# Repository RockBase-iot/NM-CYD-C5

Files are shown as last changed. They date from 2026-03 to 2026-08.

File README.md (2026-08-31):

# NM-CYD-C5

English | [中文](README_zh.md)

NM-CYD-C5 is a Cheap Yellow Display (CYD) based on ESP32-C5, supporting dual-band Wi-Fi 6 / BLE 5 / Thread / Zigbee.

This development board features an ESP32-C5 with a built-in 320 × 240 2.8" LCD touchscreen, similar to the [ESP32-Cheap-Yellow-Display](https://github.com/witnessmenow/ESP32-Cheap-Yellow-Display). The default LCD driver is ST7789, and it can also be changed to the ILI9341 driver.

# Features

The NM-CYD-C5 has the following features:

- ESP32-C5-WROOM-1, 16MB Flash and 8MB PSRAM
- 320 × 240 LCD Display (2.8")
- Resistive Touch Screen
- ESP32-C5 USB Type-C port and USB Type-C to UART port (CH340), for powering and programming
- SD Card Slot, RGB LED and some additional pins
- Fully compatible dimensions and interfaces with ESP32-Cheap-Yellow-Display, enabling seamless replacement
- FPC connector added for more convenient connection to external modules

## New Features of ESP32-C5

- ESP32-C5 RISC-V 32-bit @ 240 MHz
- Dual-Band Wi-Fi 6: 2.4GHz & 5GHz (802.11ax)
- Bluetooth 5: Classic and BLE 5 with SPP, HID, GATT support
- IEEE 802.15.4: Zigbee 3.0 end-device support
- Thread: IPv6-based mesh networking protocol

| Component | Specification |
|:---:|:---:|
| **Main SoC** | ESP32-C5 (RISC-V 32-bit, 240MHz) |
| **Wireless Protocols** | Wi-Fi 6 (802.11ax) 2.4/5GHz + BLE 5.3 + IEEE 802.15.4 |
| **Display** | 2.8" TFT, 240×320, ST7789, Touch Screen |
| **Memory** | 16MB Flash + 8MB PSRAM |
| **Interface** | 2× USB-C, GPIO, Micro SD Card Slot |

# Where to Buy

You can get the NM-CYD-C5 from the RockBase IoT AliExpress store, the RockBase IoT official website, or from NMTech Stores.

- [RockBase IoT Store](https://www.aliexpress.com/store/1105401362)
- [RockBase Shop](https://rockbase.shop/products/nm-cyd-c5)
- [NMTech Global Store](https://www.aliexpress.com/store/1104265822)
- [NMMiner](https://www.nmminer.com)

# Getting Started with Your NM-CYD-C5

For details on how to get started with your NM-CYD-C5, please check out the [Setup and Configuration](https://wiki.rockbaseiot.com/docs/products/nm-cyd-c5/) page.

To work with NM-CYD-C5, you should use the newest espressif32 library, version 3.3.5 or higher.

```ini
[env]
platform = https://github.com/pioarduino/platform-espressif32/releases/download/55.03.36/platform-espressif32.zip ; Arduino 3.3.6
```

When you use TFT_eSPI to work with the LCD, you should add `TFT_eSPI_ESP32_C5.c/h` to the Processors directory, and update `TFT_eSPI.c/h` with `CONFIG_IDF_TARGET_ESP32C5`.
These files can be found in `Demos\Arduino\libraries\TFT_eSPI`.

## Pinout of NM-CYD-C5

### Using ST7789 with XPT2046 for Touchscreen, Shared SPI

| Device | SCK | MISO | MOSI | CS | IRQ |
| --- | :---: | :---: | :---: | :---: | :---: |
| Display | 6 | 2 | 7 | 23 | --- |
| Touch | 6 | 2 | 7 | 1 | --- |
| SD Card | 6 | 2 | 7 | 10 | --- |

### LP-UART (`NM-CYD-C5:P5`) for GPS Module, e.g. `NM-ATGM336H`, Plug and Play

| Device | RX | TX | GPIO |
| --- | :---: | :---: | :---: |
| GPS | 4 | 5 | --- |

### Extend IO for I2C, `NM-CYD-C5: CN1`

| 1 | 2 | 3 | 4 |
|---|---|---|---|
| 3.3V | IO9 | IO8 | GND |

### Extend IO, `NM-CYD-C5: P1`

| 1 | 2 | 3 | 4 |
|---|---|---|---|
| IO4 | IO8 | IO26 | GND |

### NM Extend IO: 12-Pin FPC Interface, `NM-CYD-C5: FPC2`

| 1 | 2 | 3 | 4 | 5 | 6 | 7 | 8 | 9 | 10 | 11 | 12 |
|---|---|---|---|---|---|---|---|---|---|---|---|
| IO2 | IO6 | IO7 | IO10 | GND | IO4 | IO8 | IO5 | IO9 | USB D- | USB D+ | GND |

### WS2812 LEDC and Screen Backlight

| NM-CYD-C5 | Pin |
| :---: | :---: |
| IO25 | Display BL |
| IO27 | WS2812 RGB LED |

NM-CYD-C5-Pinout

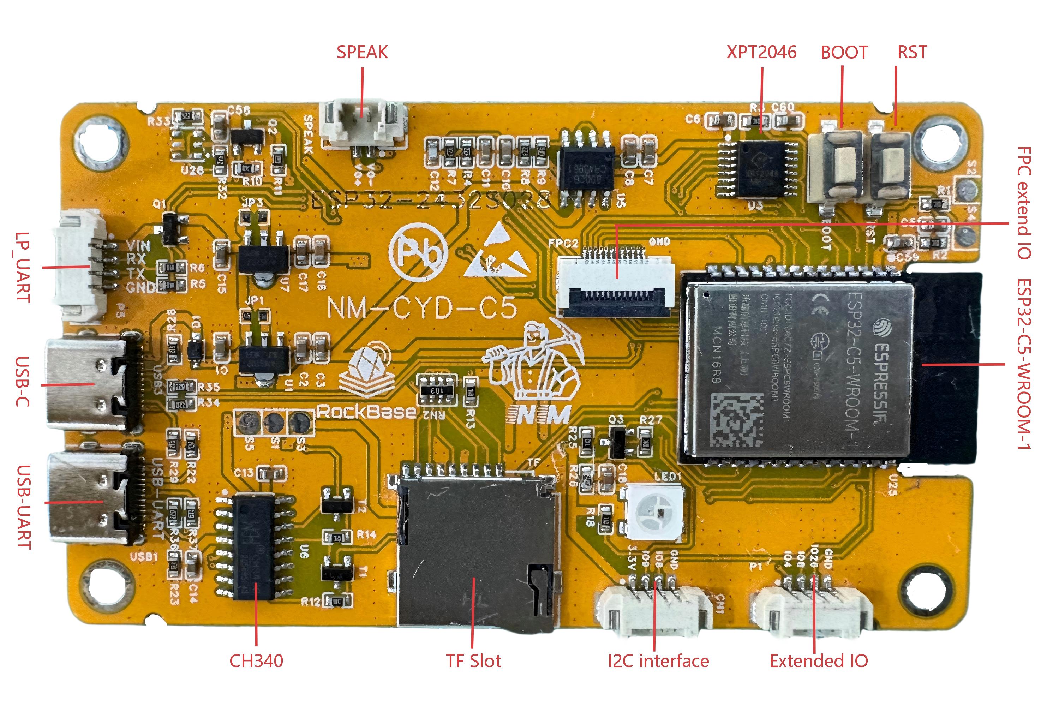
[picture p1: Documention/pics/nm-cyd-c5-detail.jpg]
NM-CYD-C5 detail


## The NM-CYD-C5 Colorful Special Edition

The [RockBase IoT Colorful Special Edition](https://rockbase.shop/products/nm-cyd-c5-colorful) will be released soon and is compatible with the standard NM-CYD-C5.

NM-CYD-C5-Color

NM-CYD-C5-Colorful

## The NM-CYD-C5 External Antenna Board

In response to widespread user demand, the latest batch of NM-CYD-C5-Colorful includes a new external-antenna design, available as an option. The NM-CYD-C5-Colorful-Ant comes with an IPEX 1 cable and a dual-band 2.4G/5G antenna, making it easy to use an external antenna. The external-antenna version of the NM-CYD-C5-Colorful delivers better Wi-Fi and BLE signal reception, making it suitable for users with higher wireless-performance requirements.

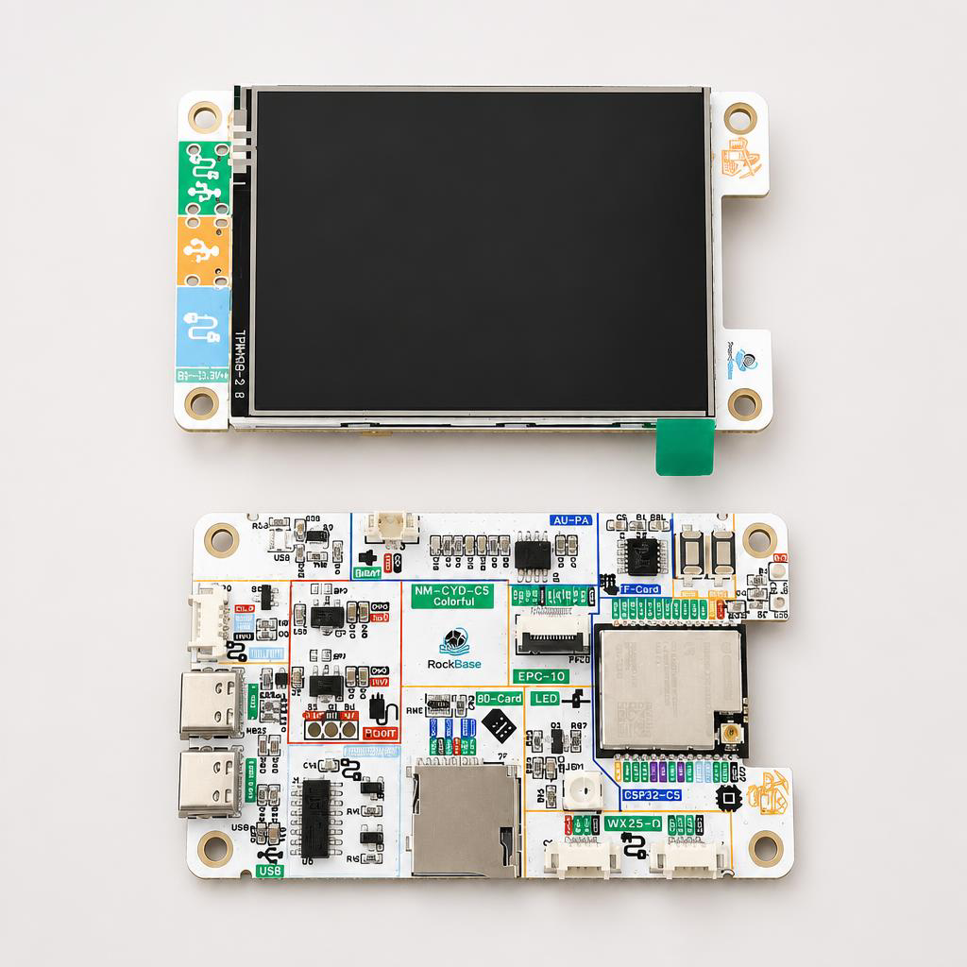
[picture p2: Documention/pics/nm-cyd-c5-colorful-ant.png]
NM-CYD-C5-Colorful-Antenna


### External Antenna Parameters

- Frequency range: 2400~2500MHz / 5000~5800MHz
- VSWR: 2400-2500 ≤ 2.5, 5000-5800 ≤ 2.5
- Efficiency %: 2400-2500: 83.3 AVG; 5000-5800: 73.8 AVG
- Peak Gain (dBi): 2400-2500: 3.2 AVG; 5000-5800: 3.7 AVG
- Radiation Properties: Omni-directional
- Polarization: Linear

<table>
  <tr>
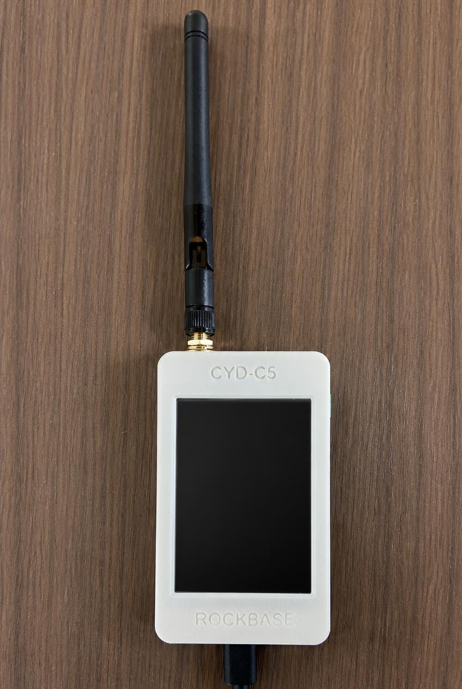
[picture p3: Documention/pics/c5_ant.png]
    <td></td>
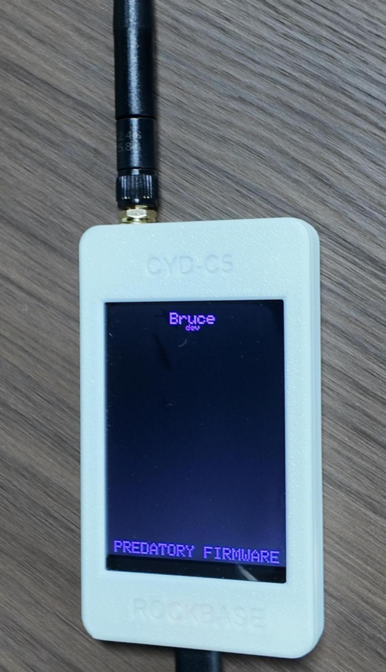
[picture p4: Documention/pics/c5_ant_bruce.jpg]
    <td></td>
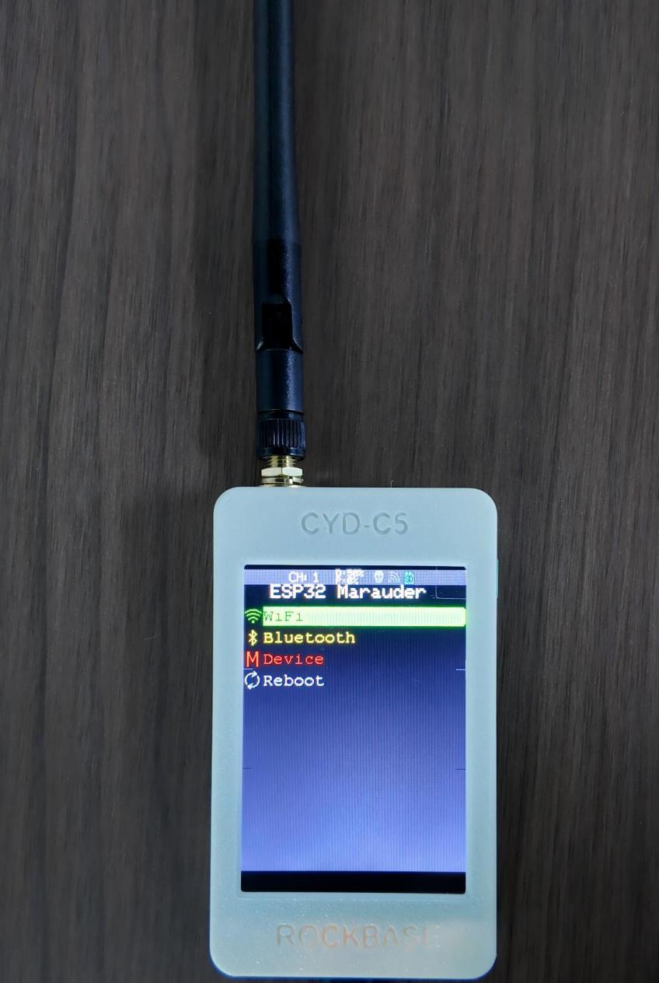
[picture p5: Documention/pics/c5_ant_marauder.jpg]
    <td></td>
  </tr>
</table>

## Compare with ESP32-2432S028

| Feature | Standard CYD (ESP32) | NM-CYD-C5 |
| :---: | :---: | :---: |
| **Wi-Fi Band** | 2.4GHz | 2.4+5GHz |
| **Wi-Fi Standard** | 802.11 b/g/n | 802.11ax (Wi-Fi 6) |
| **ZigBee** | None | ZigBee 3.0 |
| **Thread** | None | Thread 1.3 |
| **Flash** | 4MB | 16MB |
| **PSRAM** | None | 8MB |

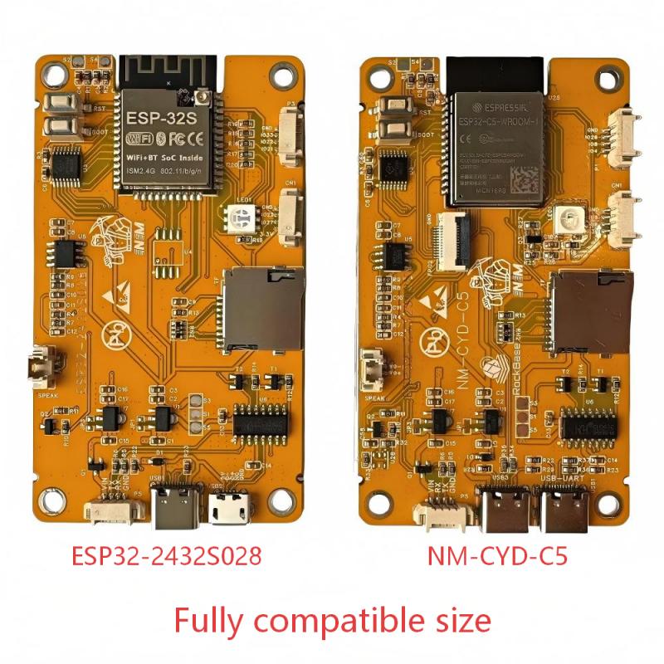
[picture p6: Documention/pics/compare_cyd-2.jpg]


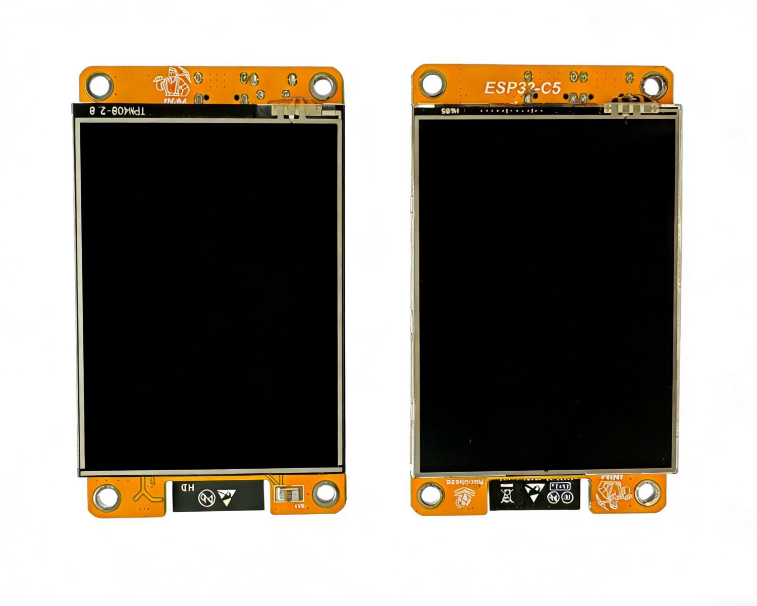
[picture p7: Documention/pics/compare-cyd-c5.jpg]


# Supported Projects

## Already Supported Projects

- [NMMiner](https://github.com/NMminer1024/NMMiner)
- [Brucefw](https://github.com/BruceDevices/firmware)
- [ESP32Marauder](https://github.com/RockBase-iot/ESP32Marauder)
- [Rogue-Radar](https://github.com/RockBase-iot/Rogue-Radar-CYD)

    Rogue Radar is a handheld ESP32 firmware that combines multiple wireless and utility tools into one rotary-driven interface.

- [CYM (Cheap Yellow Monster)](https://github.com/JimGat/CYM-NM28C5)

    Cheap Yellow Monster is a portable, touchscreen-driven WiFi security toolkit running on the NM-CYD-C5.

- [Launcher](https://github.com/RockBase-iot/Launcher)

    Application launcher for M5Stack, Lilygo, CYDs, Marauder and ESP32 devices.

- [ESP-Claw](https://github.com/espressif/esp-claw)

    ESP-Claw is Espressif's chat-coding AI agent framework for IoT devices. It defines device behavior through conversation and completes the full loop of sensing, decision-making, and execution locally on Espressif chips. Inspired by the OpenClaw concept and reimplemented in C, ESP-Claw is lightweight, intelligent, and continuously evolving.

    

    *New Version Released*: ESP-Claw 0.3.0 has been updated to support NM-CYD-C5, merging new features from `espressif/master`.

If you just want to flash the firmware, you can try the [RockBase IoT Web Flasher](https://flash.rockbaseiot.com) and choose device type `nm-cyd-c5`.

If you would like your firmware or project to run on the NM-CYD-C5, please contact the RockBase IoT team and we will assist you with adaptation and testing.

For firmware you would like to offer as a download on our Web Flasher, please check out the [ESPWebApps](https://github.com/RockBase-iot/ESPWebApps) project. ESPWebApps is a web application management platform based on ESP32 that allows users to run and manage multiple web applications on the ESP32. With ESPWebApps, you can easily share your projects with NM-CYD-C5 users, making it simple to download, install, update, and run applications on the NM-CYD-C5.

## Ongoing Projects

- [HaleHound-CYD](https://github.com/JesseCHale/HaleHound-CYD)
- [ESP32-KillerBee](https://github.com/RockBase-iot/ESP32-KillerBee)
- [ESP32DualBandWardriver](https://github.com/justcallmekoko/ESP32DualBandWardriver)

# Release Log

## 2026-08-31

- Added the external-antenna version (`NM-CYD-C5-Colorful-Ant`) description and antenna parameters.
- Added external-antenna enclosure 3MF files:
  - [nm-cyd-c5-ant-upper.3mf](Documention/3-case/nm-cyd-c5-ant-upper.3mf)
  - [nm-cyd-c5-ant-bottom.3mf](Documention/3-case/nm-cyd-c5-ant-bottom.3mf)

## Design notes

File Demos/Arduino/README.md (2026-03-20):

# How use NM-CYD-C5 with Arduino

## 1. Add ESP32 Board Support
1. Go to `File`->`Preferences`

2. Add to "Additional Boards Manager URLs":

   ```
   https://espressif.github.io/arduino-esp32/package_esp32_index.json
   ```

3. Go to `Tools`->`Board`->`Boards Manager`

4. Search "ESP32" and install "ESP32 by Espressif Systems", the version 3.3.5 or a higher version can support ESP32-C5.

5. Then choose `ESP32C5 Dev Module` from `Tools`->`Board`->`esp32`->`ESP32C5 Dev Module`.

## 2. Install the libraries

Arduino IDE Libray Manger, Install the libraries below:

 - `TFT_eSPI` by Bodmer
 - `XPT2046_Touchscreen` by Paul Stoffregen

## 3. The `libraries\TFT_eSPI\User_Setup.h` change to NM-CYD-C5

```c
#define ST7789_DRIVER

#define TFT_BL   25            // LED back-light control pin
#define TFT_BACKLIGHT_ON HIGH  // Level to turn ON back-light (HIGH or LOW)

#define TFT_MISO  2
#define TFT_MOSI  7
#define TFT_SCLK  6
#define TFT_CS    23  // Chip select control pin
#define TFT_DC    24  // Data Command control pin
#define TFT_RST  -1  // Set TFT_RST to -1 if display RESET is connected to ESP32 board RST

// share SPI with TFT
#define TOUCH_CS 1     // Chip select pin (T_CS) of touch screen

#define SPI_FREQUENCY  20000000
// Optional reduced SPI frequency for reading TFT
#define SPI_READ_FREQUENCY  20000000
// The XPT2046 requires a lower SPI clock rate of 2.5MHz so we define that here:
#define SPI_TOUCH_FREQUENCY  2500000
```

# To develop ZigBee with NM-CYD-C5

1. Choose ZigBee mode: `Tools`->`ZigBee Mode`, choose the mode you want, `Zigbee ED(End Device)`, will set ESP32-C5 as a ZigBee End Device.

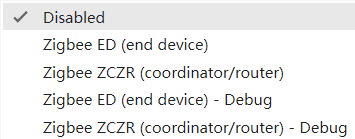
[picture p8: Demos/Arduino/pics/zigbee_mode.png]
Zigbee Mode


2. Choose Partition Scheme: `Tools`->`Partition Scheme` to `Zigbee 8MB with spiffs`.

## Zigbee Overview

Zigbee is a low-power, low-bandwidth wireless communication protocol based on the IEEE 802.15.4 stardard. It is used for IoT scenarios such as home automation, smart cities, and industrial control, offering robust mesh networking capabilities for reliable communication in dynamic environments.

Zigbee communication relies on the Zigbee Cluster Library (ZCL), which defines how devices organize their functionality and interact.

## Zigbee Network Architecture

 - Zigbee Coordinator (ZC)
 - Zigbee Router (ZR)
 - Zigbee End Device (ZED)

Espressif examples of Zigbee can get from github: [Arduino-esp32 Zigbee Examples](https://github.com/espressif/arduino-esp32/tree/master/libraries/Zigbee/examples)

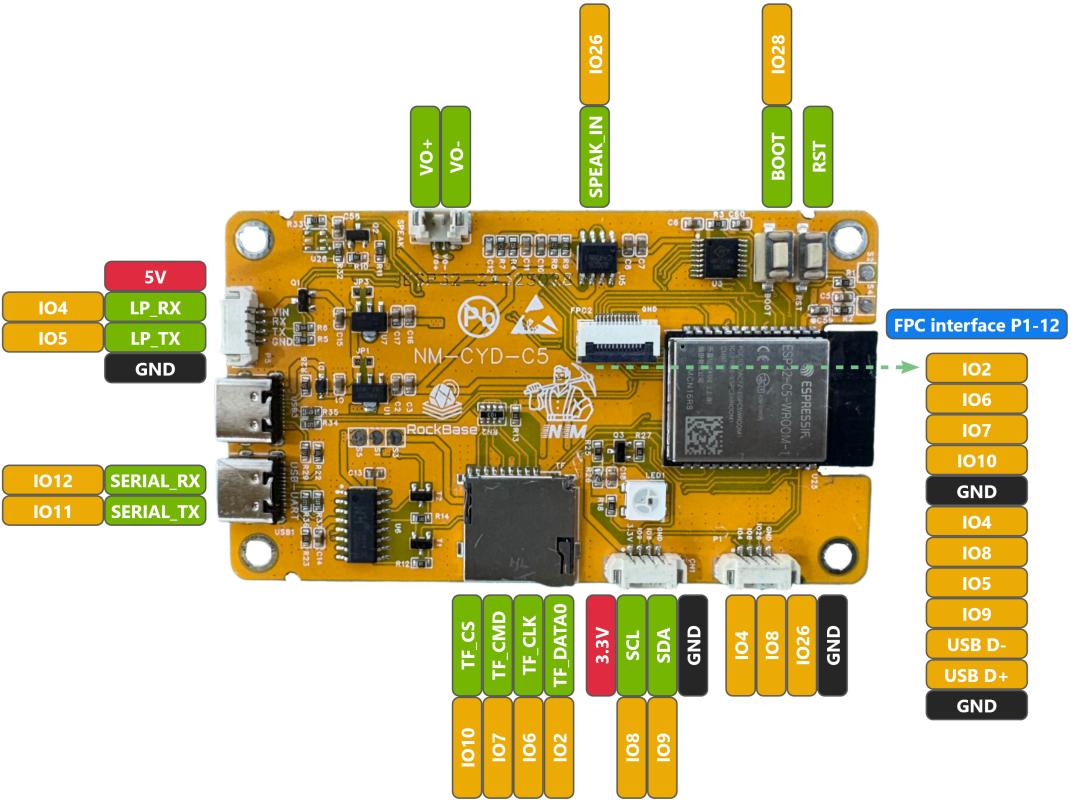
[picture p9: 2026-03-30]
Documention/pics/NM-CYD-C5-pinout-800.jpg

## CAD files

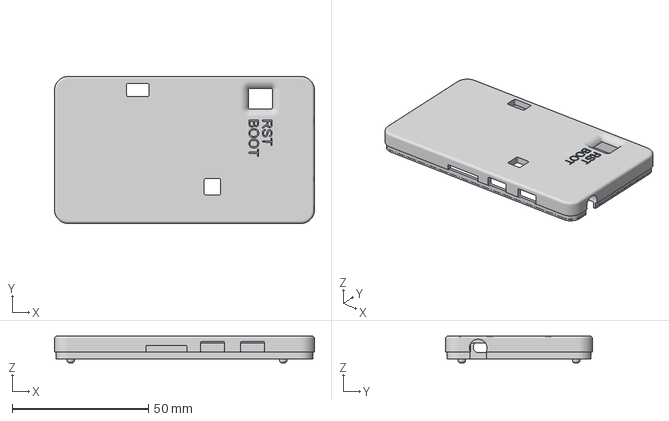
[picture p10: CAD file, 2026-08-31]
Documention/3-case/nm-cyd-c5-ant-bottom.3mf
95.5 x 54.0 x 9.91 mm

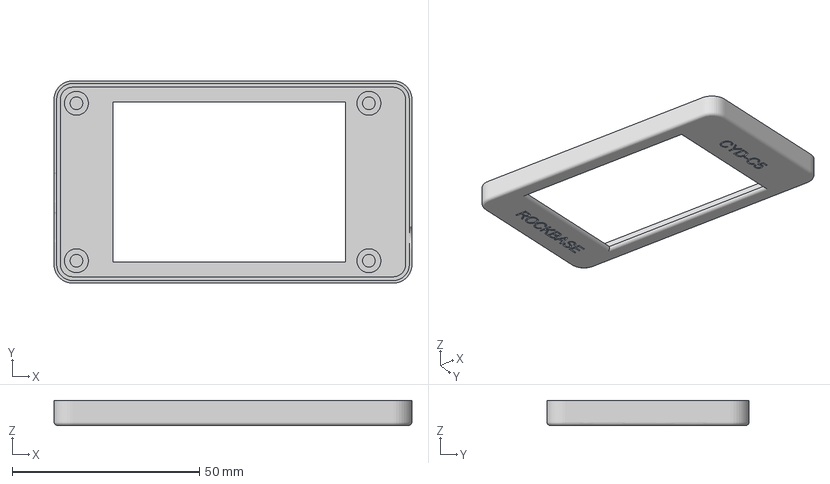
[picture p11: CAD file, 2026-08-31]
Documention/3-case/nm-cyd-c5-ant-upper.3mf
95.5 x 54.0 x 6.70 mm

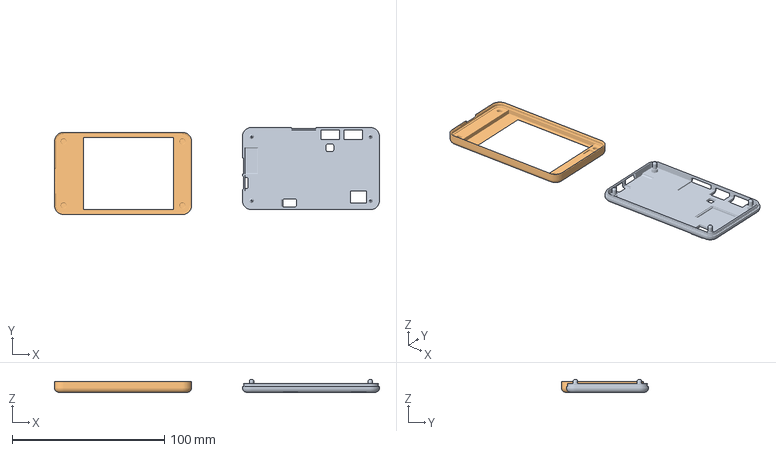
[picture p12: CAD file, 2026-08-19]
Documention/3-case/nm-cyd-c5-case.3mf
213.4 x 57.2 x 8.40 mm
组合体
CYD_Case(1).stl_1

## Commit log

2026-04-15 Update README with new supported project links and descriptions
    Added links and descriptions for ESP32Marauder, Launcher and Rogue-Radar projects.
2026-08-19 Add NM-CYD-C5-Colorful-Ant board, add 3D case demo
    [nm-cyd-c5-case.3mf]
2026-08-31 open-source nm-cyd-c5-ant external case 3mf files
    [nm-cyd-c5-ant-bottom.3mf, nm-cyd-c5-ant-upper.3mf]
